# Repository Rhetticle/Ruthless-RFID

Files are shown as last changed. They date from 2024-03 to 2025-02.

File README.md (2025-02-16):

# Ruthless RFID

<p align="center">
  
</p>

# Overview
ISO/IEC 14443 compliant homemade RFID reader and writer for MIFARE Ultralight cards. Capable of writing stored data to new cards, storing read card data into flash memory as well as cloning from one card to another.

# Hardware Details
* RF Transceiver - NXP Semicondutors MFRC522 (QFN32)
* Microcontroller - ST Microelectronics STM32F401CBU6 (QFN48)
* OLED Display - Adafruit 5228
* Flash memory - Winbond W25N01GVZEIG (1 GBit) (8WSON)

Check out [Ruthless RFID Altium](https://github.com/TheZ0/Ruthless-RFID/tree/master/Ruthless%20RFID%20Altium) for PCB design and layout.

# Firmware Details
Firmware for the Ruthless RFID was created using the STM32CubeIDE. The Ruthless RFID is running FreeRTOS to separate each functionality shown on the home screen into it's own task as well as some background tasks such as listening for USB input.
## Drivers
* RF Transceiver - [MFRC.c](https://github.com/TheZ0/Ruthless-RFID/blob/master/Firmware/Ruthless%20RFID/Core/Src/MFRC.c) , [MFRC.h](https://github.com/TheZ0/Ruthless-RFID/blob/master/Firmware/Ruthless%20RFID/Core/Inc/MFRC.h)
* OLED Display - [OLED.c](https://github.com/TheZ0/Ruthless-RFID/blob/master/Firmware/Ruthless%20RFID/Core/Src/OLED.c) , [OLED.h](https://github.com/TheZ0/Ruthless-RFID/blob/master/Firmware/Ruthless%20RFID/Core/Inc/OLED.h)
* Flash memory - [W25N01GVZEIG.c](https://github.com/TheZ0/Ruthless-RFID/blob/master/Firmware/Ruthless%20RFID/Core/Src/W25N01GVZEIG.c) , [W25N01GVZEIG.h](https://github.com/TheZ0/Ruthless-RFID/blob/master/Firmware/Ruthless%20RFID/Core/Inc/W25N01GVZEIG.h)

## RuthlessFS
The Ruthless RFID uses a basic file system RuthlessFS to store and organise data read from a physical card or uploaded via USB by user. Each file occupies a 128KiB block (smallest erasable block size) and contains data such as PICC type, UID and raw contents. Checkout [ruthlessfs.c](https://github.com/TheZ0/Ruthless-RFID/blob/master/Firmware/Ruthless%20RFID/Core/Src/ruthlessfs.c) , [ruthlessfs.h](https://github.com/TheZ0/Ruthless-RFID/blob/master/Firmware/Ruthless%20RFID/Core/Inc/ruthlessfs.h) for more info.

## Terminal
Ruthless RFID has a basic command line interface which the user can interact with using a terminal emulator such as PuTTy or similar. This interface supports common commands such as `ls`, `rm` and `cat` as well as two custom commands `pg` (program) for user to input their own file and `mod` for user to modify an existing file (See below).




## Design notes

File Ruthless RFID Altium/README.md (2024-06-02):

# Overview
The PCB and schematic for the Ruthless RFID were made in Altium Designer.

# Schematic Notes


For designs which do not use the coil design used in this repository it is recommended that close attention is paid to the RF section of the MFRC522. Variations in coil design will have significant impact on the matching network C20 - C27. The filtering section (L1,C21) and (L2,C26) do not depend on coil design but should be chosen to have a resonant frequency of 13.56MHz). See [AN11564](https://www.nxp.com/docs/en/application-note/AN11564.pdf) from NXP for more details on the matching network.

# PCB Notes



The PCB is two layers with 3V3 plane on top and GND plane below. 

Important Layout Points
* Keep matching capacitors as close coil as possible to coil
* Ensure filter inductors L1,L2 are placed as close to MFRC522 as possible
* Keep return GND traces from matching and filtering components as short as possible
* Ensure no copper fills are above or below coil

# Manufacturing Details
Gerber files for the PCB can be found in Project Outputs/RFID.zip.

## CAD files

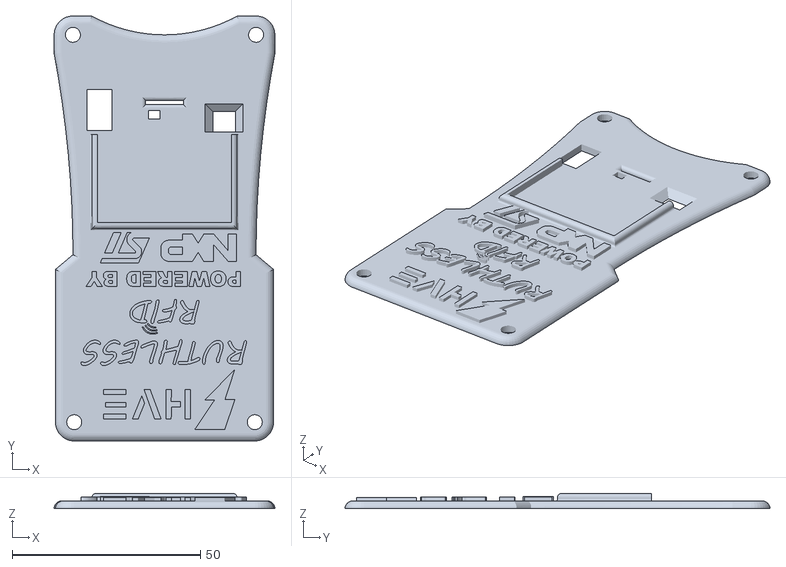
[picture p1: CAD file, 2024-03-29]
Casing STL files/ruthlessRFID top.stl
58.7 x 112.9 x 4.00

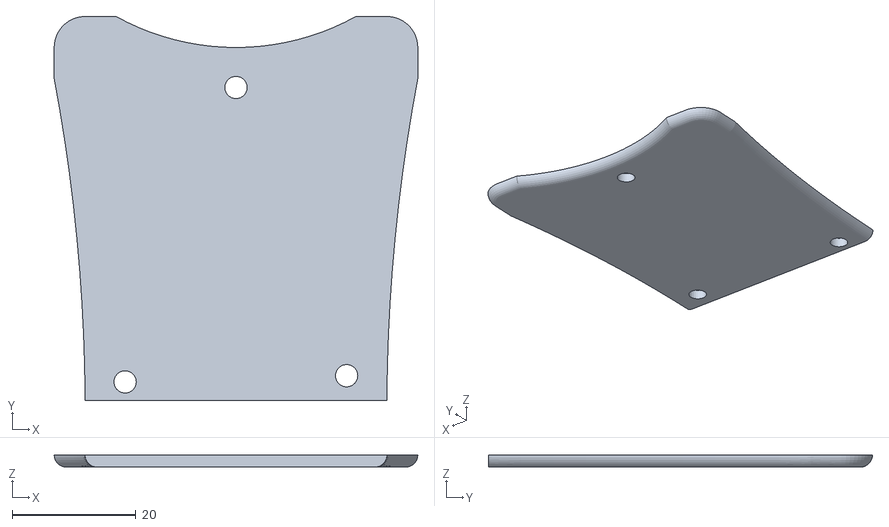
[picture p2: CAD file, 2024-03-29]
Casing STL files/RuthlessRFID slot.stl
58.7 x 61.9 x 2.00

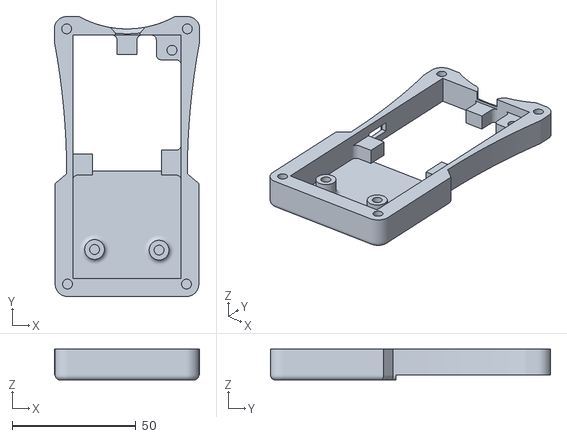
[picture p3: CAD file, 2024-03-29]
Casing STL files/RuthlessRFID base.stl
58.7 x 112.9 x 12.5

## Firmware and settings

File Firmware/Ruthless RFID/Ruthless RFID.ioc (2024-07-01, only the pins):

Mcu.UserName=STM32F401CBUx
PA1.GPIO_Label=BUTTON (EXTI1)
PA1.Signal=GPXTI1
PA11.Signal=USB_OTG_FS_DM
PA12.Signal=USB_OTG_FS_DP
PA13.Signal=SYS_JTMS-SWDIO
PA14.Signal=SYS_JTCK-SWCLK
PA2.Signal=S_TIM2_CH3
PA3.GPIO_Label=OLED_RST
PA3.Signal=GPIO_Output
PA4.GPIO_Label=CS_OLED
PA4.Signal=GPIO_Output
PA5.Signal=SPI1_SCK
PA7.Signal=SPI1_MOSI
PA8.GPIO_Label=CS_MEM
PA8.Signal=GPIO_Output
PB1.Signal=GPIO_Output
PB10.Signal=SPI2_SCK
PB14.Signal=SPI2_MISO
PB15.Signal=SPI2_MOSI
PB5.GPIO_Label=MFRC_NRST
PB5.Signal=GPIO_Output
PB6.Signal=I2C1_SCL
PB7.Signal=I2C1_SDA

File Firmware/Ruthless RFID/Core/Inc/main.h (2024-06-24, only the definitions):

#define BUTTON_Pin GPIO_PIN_1
#define BUTTON_GPIO_Port GPIOA
#define BUTTON_EXTI_IRQn EXTI1_IRQn
#define OLED_RST_Pin GPIO_PIN_3
#define OLED_RST_GPIO_Port GPIOA
#define CS_OLED_Pin GPIO_PIN_4
#define CS_OLED_GPIO_Port GPIOA
#define CS_MEM_Pin GPIO_PIN_8
#define CS_MEM_GPIO_Port GPIOA
#define MFRC_NRST_Pin GPIO_PIN_5
#define MFRC_NRST_GPIO_Port GPIOB

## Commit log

2024-03-29 Fixed hardfault during ReadCard task
    [OLED.c, OLED.h, Ruthless RFID.ioc]
2024-04-09 Fixed footprint name errors
    [RFID Sheet 1.SchDoc, RFID Sheet2.SchDoc, RFID.PrjPcb]
2024-04-14 Reverted back to old task structure
    [Ruthless RFID.ioc]
2024-04-15 Moved button checking into it's own function
2024-06-02 Write card screen working
    [PCB1.GBL, PCB1.GBO, PCB1.GBP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]
2024-06-13 Fixed col and page address bug. Part has zero bad blocks
    [W25N01GVZEIG.c]
2024-06-14 Fixed hard fault when reading sector
    [W25N01GVZEIG.c]
2024-06-15 Fixed bug in f_open usage. FATFS object needs to be global or static (Cannot repeatedly mount new file systems
2024-06-22 Fixed memory leak in OLED_display_files(). Able to read and store multiple cards
    [OLED.c, OLED.h]
2024-06-24 Begun refactoring user button to use interrupts
2024-06-24 Most tasks refactored. Fixed memory leak in UL_readcard()
    [MFRC.c, Ruthless RFID.ioc]
2024-06-26 Fixed not being able to write to last page of ultralight card
    [MFRC.c]
2024-06-26 Added used and free data to show files, task is still buggy
    [OLED.c, ruthlessfs.c]
2024-06-27 Fixed suspend/resume bug. Increased ReadCard, ShowFiles, ShowFileData stack sizes to 512 words
    [Ruthless RFID.ioc]
2024-06-28 Modified button ISR to reduce false long presses
2024-06-30 Fixed delay in _write for printf
    [Ruthless RFID.ioc]
2024-07-02 rm working. Error handling still needed
    [ruthlessfs.c]
2024-07-03 Able to program file using pg, still needs error handling
    [ruthlessfs.c]
2024-07-03 Fixed bugs with mod command
    [ruthlessfs.c]
2024-07-04 Fixed bug in OLED_SELECT()
    [OLED.c]
2024-07-05 Fixed memory leak in UL_verify()
    [MFRC.c]
2024-07-05 Fixed free() bug in remove_card_byname()
    [ruthlessfs.c]

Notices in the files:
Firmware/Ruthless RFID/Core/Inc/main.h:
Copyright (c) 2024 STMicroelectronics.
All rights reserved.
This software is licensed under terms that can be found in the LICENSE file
